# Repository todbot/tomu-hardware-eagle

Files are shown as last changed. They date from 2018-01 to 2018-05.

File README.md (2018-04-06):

# tomu-hardware-eagle

My attempt at translating the wonderful [im-tomu/tomu-hardware](https://github.com/im-tomu/tomu-hardware) project ([crowdfunding now on CrowdSupply!](https://www.crowdsupply.com/sutajio-kosagi/tomu/)) from Kicad into Eagle.

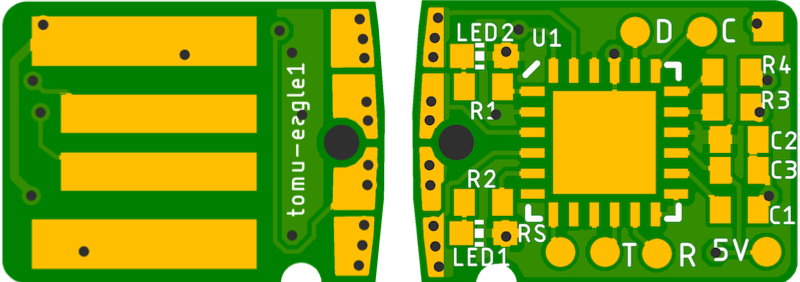
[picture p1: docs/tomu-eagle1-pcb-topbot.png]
tomu-eagle1-topbot

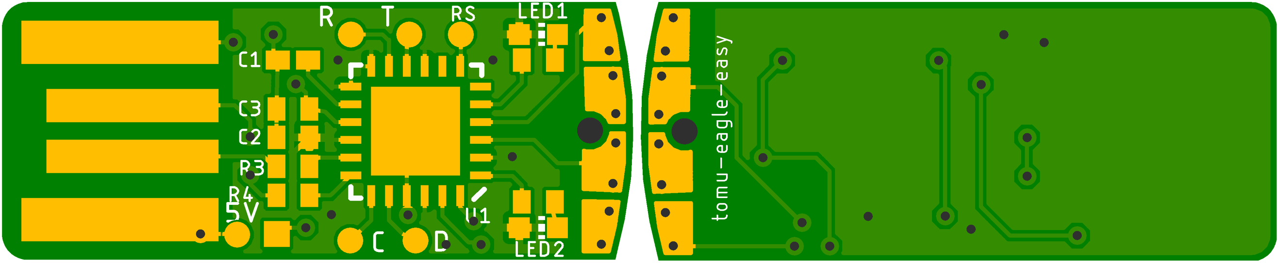
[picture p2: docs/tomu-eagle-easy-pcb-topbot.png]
tomu-eagle-easy-topbot

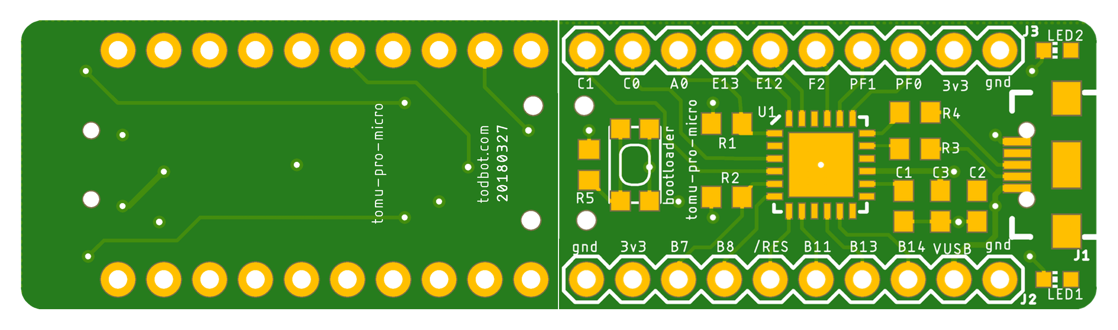
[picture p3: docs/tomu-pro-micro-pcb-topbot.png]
tomu-pro-micro


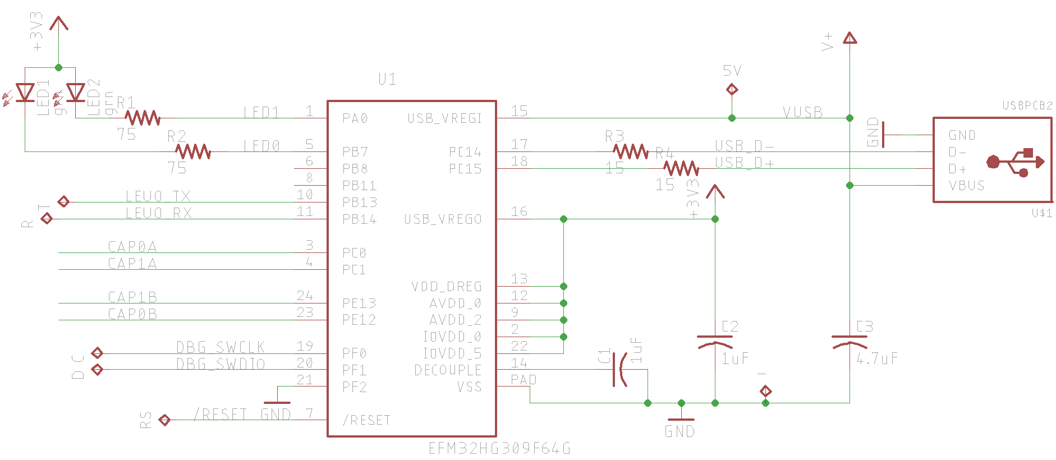
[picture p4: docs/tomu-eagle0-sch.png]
tomu-eagle0-sch

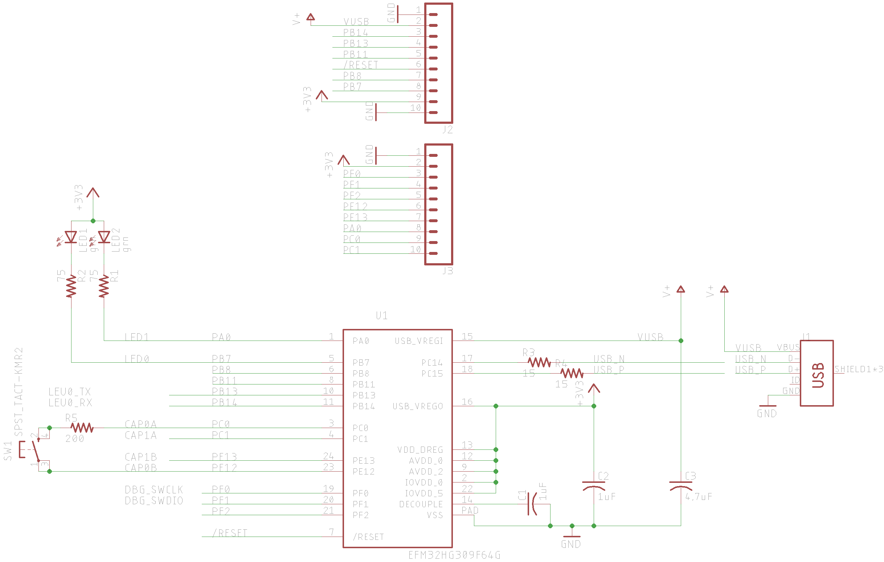
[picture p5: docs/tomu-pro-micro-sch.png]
tomu-pro-micro-sch


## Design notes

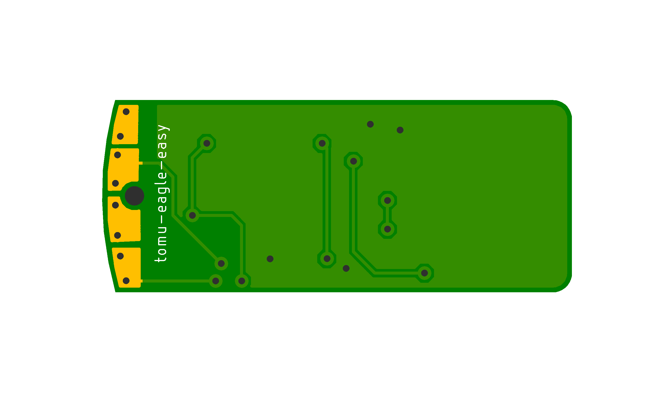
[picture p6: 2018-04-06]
docs/tomu-eagle-easy-pcb-bot.png

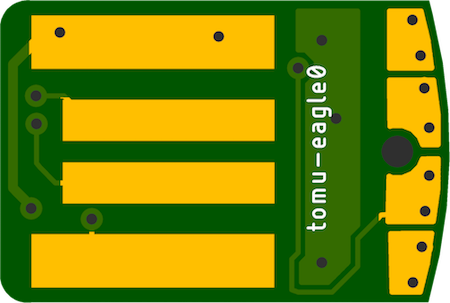
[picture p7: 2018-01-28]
docs/tomu-eagle0-pcb-top.png

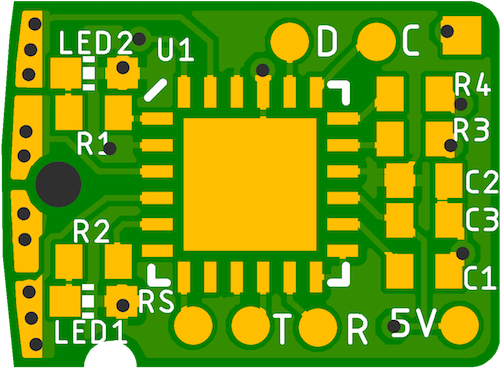
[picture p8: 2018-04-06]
docs/tomu-eagle1-pcb-bot.png

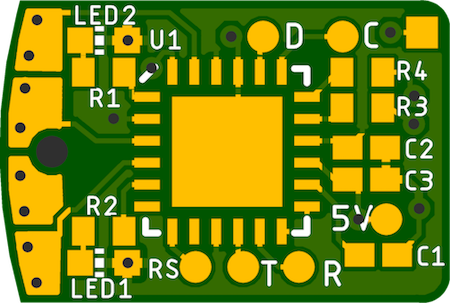
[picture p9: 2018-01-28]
docs/tomu-eagle0-pcb-bot.png

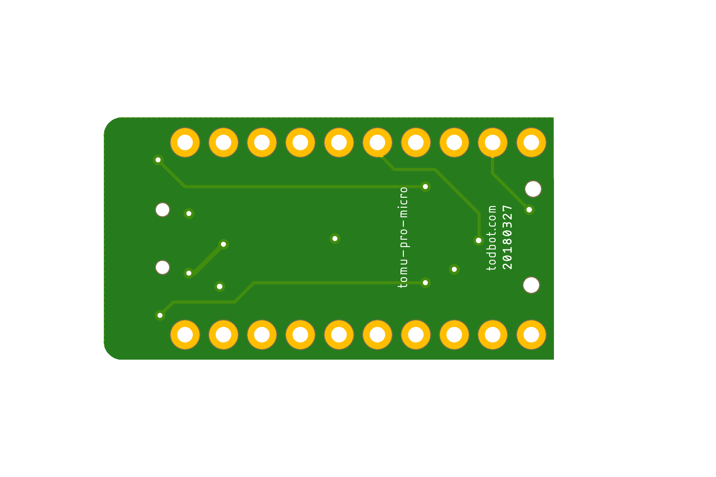
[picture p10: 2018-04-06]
docs/tomu-pro-micro-pcb-bot.png

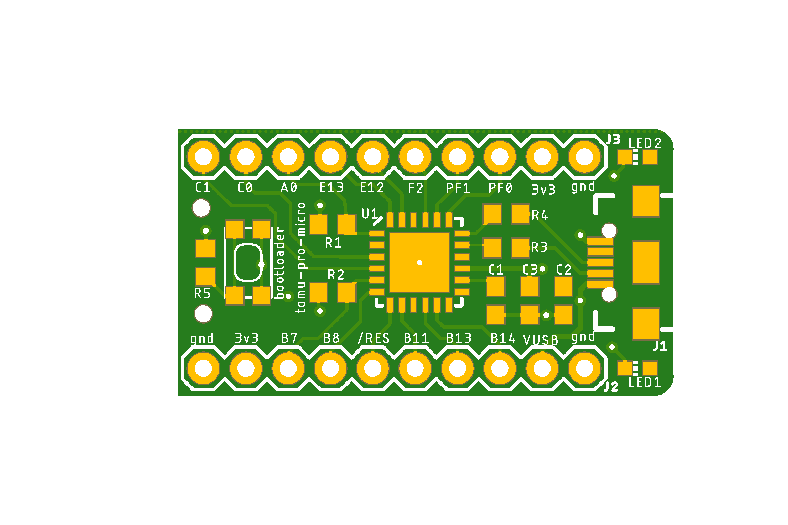
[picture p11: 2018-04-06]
docs/tomu-pro-micro-pcb-top.png

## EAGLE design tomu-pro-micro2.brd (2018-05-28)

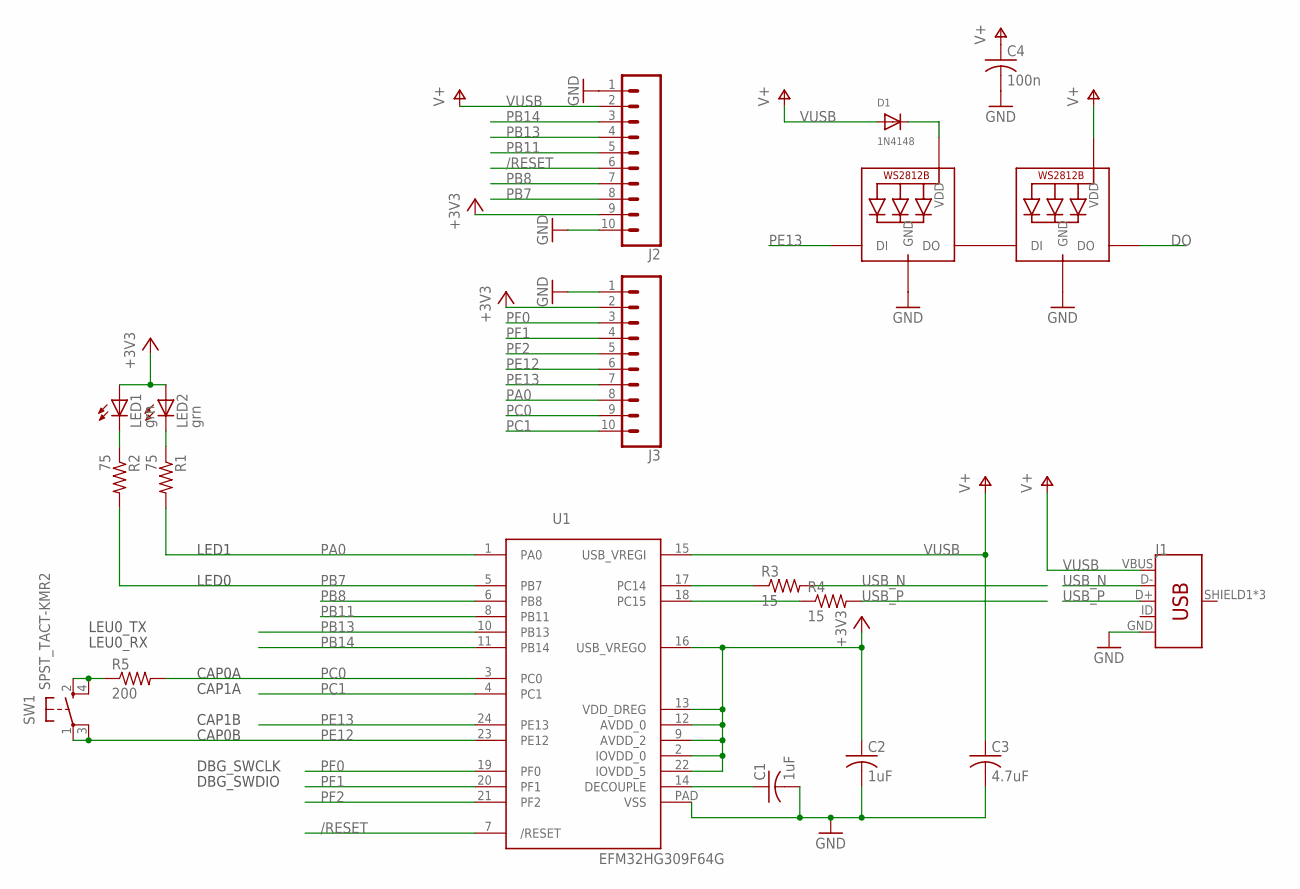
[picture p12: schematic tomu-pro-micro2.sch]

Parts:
C1, C2: 1uF; C0603
C3: 4.7uF; C0603
C4: 100n; C0603
D1: 1N4148; SOD-323F
J1: USB_MICRO-B_FEMALE-SMT; USB-B-MICRO-SMD
J2, J3: CONN_10"; 1X10
L1, L2: WS2812B3535; LED3535
LED1, LED2: grn; CHIP-LED0603
R1, R2: 75; R0603
R3, R4: 15; R0603
R5: 200; R0603
SW1: SPST_TACT-KMR2; KMR2
U1: EFM32HG309F64G; QFN24PAD

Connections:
+3V3: C2.1, J2.9, J3.2, LED1.A, LED2.A, U1.2 (IOVDD_0), U1.9 (AVDD_2), U1.12 (AVDD_0), U1.13 (VDD_DREG), U1.16 (USB_VREGO), U1.22 (IOVDD_5)
/RESET: J2.6, U1.7 (/RESET)
DECOUPLE: C1.1, U1.14 (DECOUPLE)
DO: L2.3 (DO)
GND: C1.2, C2.2, C3.2, C4.2, J1.GND, J2.1, J2.10, J3.1, L1.4 (GND), L2.4 (GND), U1.PAD (VSS)
unnamed: L1.3 (DO), L2.1 (DI)
unnamed: D1.C, L1.2 (VDD)
unnamed: LED1.C, R2.1
unnamed: LED2.C, R1.1
unnamed: R5.1, SW1.2 (S), SW1.4 (S1)
PA0: J3.8, R1.2, U1.1 (PA0)
PB7: J2.8, R2.2, U1.5 (PB7)
PB8: J2.7, U1.6 (PB8)
PB11: J2.5, U1.8 (PB11)
PB13: J2.4, U1.10 (PB13)
PB14: J2.3, U1.11 (PB14)
PC0: J3.9, R5.2, U1.3 (PC0)
PC1: J3.10, U1.4 (PC1)
PE12: J3.6, SW1.1, SW1.3 (P1), U1.23 (PE12)
PE13: J3.7, L1.1 (DI), U1.24 (PE13)
PF0: J3.3, U1.19 (PF0)
PF1: J3.4, U1.20 (PF1)
PF2: J3.5, U1.21 (PF2)
RUSB_N: R3.1, U1.17 (PC14)
RUSB_P: R4.1, U1.18 (PC15)
USB_N: J1.D-, R3.2
USB_P: J1.D+, R4.2
VUSB: C3.1, C4.1, D1.A, J1.VBUS, J2.2, L2.2 (VDD), U1.15 (USB_VREGI)

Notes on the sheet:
LED1
LED0
DBG_SWCLK
DBG_SWDIO
LEU0_TX
LEU0_RX
CAP0A
CAP1A
CAP1B
CAP0B

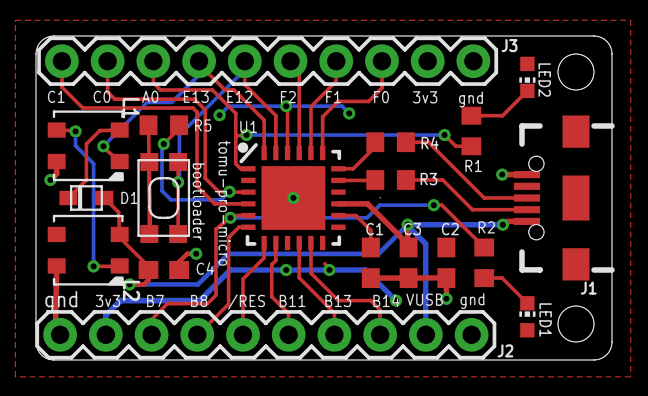
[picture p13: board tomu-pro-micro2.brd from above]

Board: 2 copper layers, 32.0 x 18.0 mm, 19 parts (0 on the bottom side), 27 nets.

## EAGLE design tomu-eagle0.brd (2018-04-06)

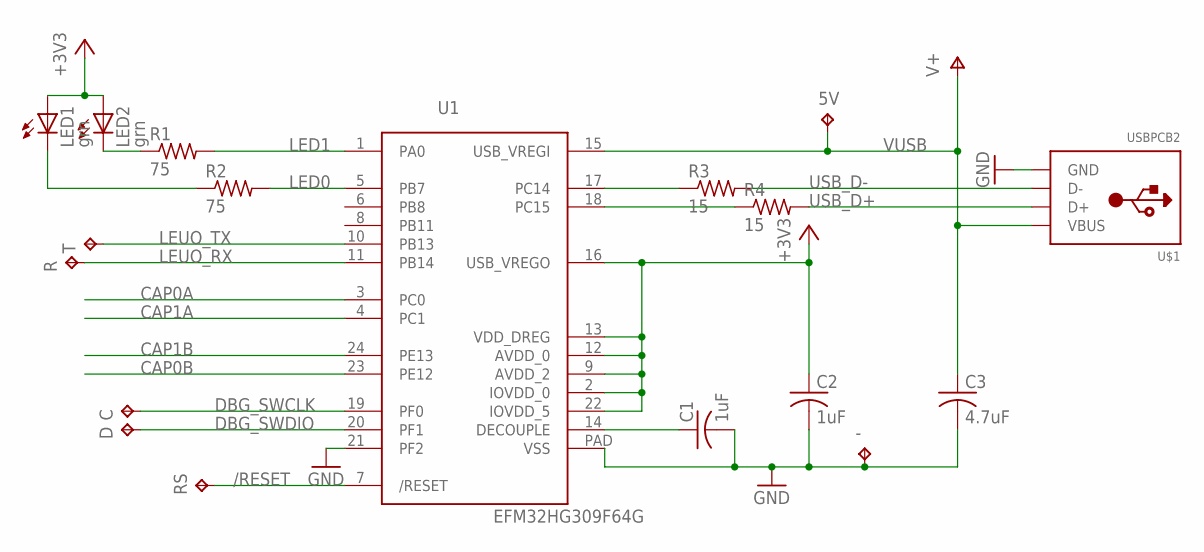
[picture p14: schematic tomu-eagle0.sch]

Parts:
5V: TPTP10R; TP10R
-: TPTP10SQ; TP10SQ
C: TPTP10R; TP10R
C1, C2: 1uF; C0402K
C3: 4.7uF; C0402K
D: TPTP10R; TP10R
LED1, LED2: grn; CHIP-LED0603
R: TPTP10R; TP10R
R1, R2: 75; R0402
R3, R4: 15; R0402
RS: TPTP10R; TP10R
T: TPTP10R; TP10R
U1: EFM32HG309F64G; QFN24PAD
U$1: USBPCB2; USB-A-PCB-2

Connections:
+3V3: C2.1, LED1.A, LED2.A, U1.2 (IOVDD_0), U1.9 (AVDD_2), U1.12 (AVDD_0), U1.13 (VDD_DREG), U1.16 (USB_VREGO), U1.22 (IOVDD_5)
/RESET: RS.TP, U1.7 (/RESET)
CAP0A: U1.3 (PC0)
CAP0B: U1.23 (PE12)
CAP1A: U1.4 (PC1)
CAP1B: U1.24 (PE13)
DBG_SWCLK: C.TP, U1.19 (PF0)
DBG_SWDIO: D.TP, U1.20 (PF1)
DECOUPLE: C1.1, U1.14 (DECOUPLE)
GND: -.TP, C1.2, C2.2, C3.2, U1.21 (PF2), U1.PAD (VSS), U$1.GND
LED0: R2.2, U1.5 (PB7)
LED1: R1.2, U1.1 (PA0)
LEUO_RX: R.TP, U1.11 (PB14)
LEUO_TX: T.TP, U1.10 (PB13)
unnamed: LED1.C, R2.1
unnamed: LED2.C, R1.1
RUSB_D+: R4.1, U1.18 (PC15)
RUSB_D-: R3.1, U1.17 (PC14)
USB_D+: R4.2, U$1.USB_P (D+)
USB_D-: R3.2, U$1.USB_M (D-)
VUSB: 5V.TP, C3.1, U1.15 (USB_VREGI), U$1.5V (VBUS)

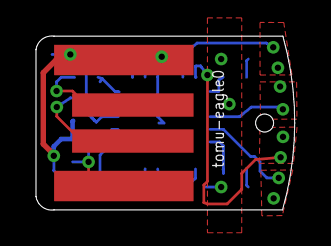
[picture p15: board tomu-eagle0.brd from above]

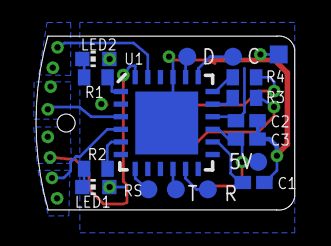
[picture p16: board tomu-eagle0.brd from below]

Board: 2 copper layers, 14.4 x 9.7 mm, 18 parts (17 on the bottom side), 17 nets.

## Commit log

2018-01-26 added first pass at touch sensors
    [tomu-eagle0.brd, tomu-eagle0.sch]
2018-01-26 fixed up touch sensor
    [tomu-eagle0.brd, tomu-eagle0.sch]
2018-01-26 minor cleanup
    [tomu-eagle0.brd]
2018-01-26 sigh. QFN24 is 5x5 not 4x4
    [tomu-eagle0.brd, tomu-eagle0.sch]
2018-01-26 still dealing with QFN 4x4 -> 5x5 issues
    [tomu-eagle0.brd, tomu-eagle0.sch]
2018-01-26 fix CAP1A/CAP1B positions
    [tomu-eagle0.brd]
2018-01-27 added first pass at "easy" version
    [tomu-eagle-easy.brd, tomu-eagle-easy.sch]
2018-01-28 more fixes
    [tomu-eagle-easy.brd, tomu-eagle-easy.sch, tomu-eagle0.brd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]
2018-02-01 added tomu-eagle1, more faithful to original tomu 0.4
    [tomu-eagle1.brd, tomu-eagle1.sch]
2018-02-01 fixes to tomu-eagle1
    [tomu-eagle1.brd, tomu-eagle1.sch]
2018-02-01 more fixes to tomu-eagle1
    [tomu-eagle1.brd]
2018-02-01 more fixes, update readme
    [tomu-eagle1.brd, tomu-eagle1.sch]
2018-02-10 small updates to tomu-eagle-easy
    [tomu-eagle-easy.brd, tomu-eagle-easy.sch]
2018-03-27 added tomo-pro-micro breakout board
    [tomu-eagle-easy.brd, tomu-pro-micro.brd, tomu-pro-micro.sch]
2018-04-06 added tomu-pro-micro docs
    [tomu-pro-micro.brd]
2018-04-06 LED resistors should be 75 not 15 (or maybe 52 as in the tomu bom)
    [tomu-eagle-easy.brd, tomu-eagle-easy.sch, tomu-eagle0.brd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]
2018-05-20 added tomu-pro-micro1 board
    [tomu-pro-micro1.brd, tomu-pro-micro1.sch]
2018-05-22 fix EFM32HG309 QFN pad spacing issue. omg what a slog
    [tomu-pro-micro1.brd, tomu-pro-micro1.sch]
2018-05-28 fix problems with tomo-pro-micro1
    [tomu-pro-micro2.brd, tomu-pro-micro2.sch]

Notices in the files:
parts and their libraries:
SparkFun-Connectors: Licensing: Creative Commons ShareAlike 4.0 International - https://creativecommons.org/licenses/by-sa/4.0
